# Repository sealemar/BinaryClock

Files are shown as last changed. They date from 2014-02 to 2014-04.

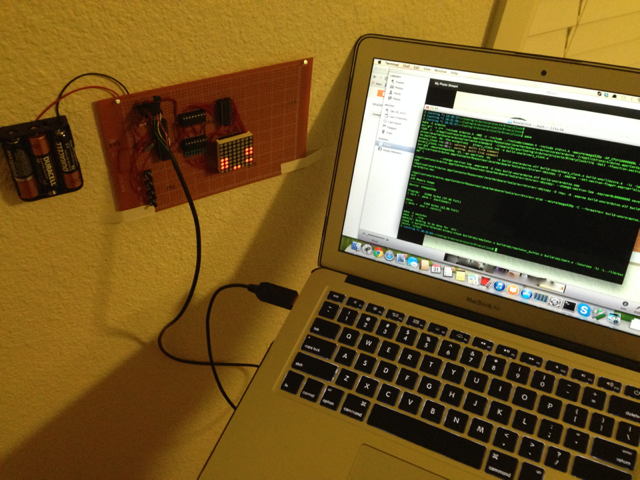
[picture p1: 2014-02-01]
doc/photos/BinaryClockProgramming.jpg

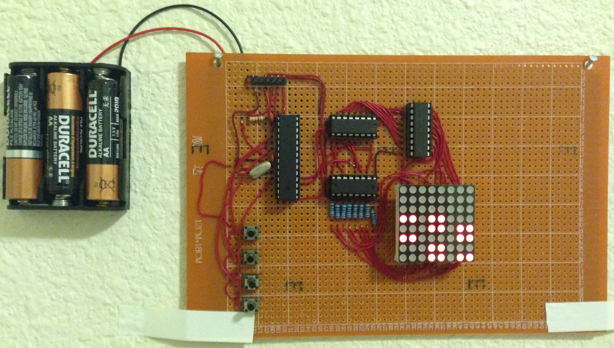
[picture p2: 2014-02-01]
doc/photos/BinaryClock.jpg

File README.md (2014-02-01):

BinaryClock
===========

More about the project is on my blog:

- [I talk about software](http://sealemar.blogspot.com/2014/02/binaryclock-binary-clock-diy.html)
- [I talk about hardware](http://sealemar.blogspot.com/2014/02/binaryclock-hardware.html)

Here I talk only about the tools which you will need to compile the software.

Tools I will need
-----------------

This is a list of tools you will (or may) need to work with the code. This list is described in more details on the [blog](http://sealemar.blogspot.com).

- [Make](http://www.gnu.org/software/make/manual/make.html) (*comes with every Unix based OS - Linux/Mac, etc.*)
- [Arduino software](http://arduino.cc/en/Main/Software)
- [Makefile by Sudar / Martin Oldfield](https://github.com/sudar/Arduino-Makefile)
- [colorgcc](https://github.com/colorgcc/colorgcc) (*optional, but is very handy when it comes to compiling code in the console/terminal*)
- [Exuberant ctags](http://ctags.sourceforge.net/) (*optional, but is very handy especially when it comes to Emacs or ViM*)

**For the emulator and tests:**
- gcc / clang (*at least one of these comes with every Unix based OS - Linux - gcc, MacOs - clang*)

**For the emulator:**
- ncurses (*comes with every Unix based OS*)

**For the vimproject (optional - read on):**
- ViM, [MacVim](https://code.google.com/p/macvim) for Mac

**For the schematic:**
- [Fritzing](http://fritzing.org)

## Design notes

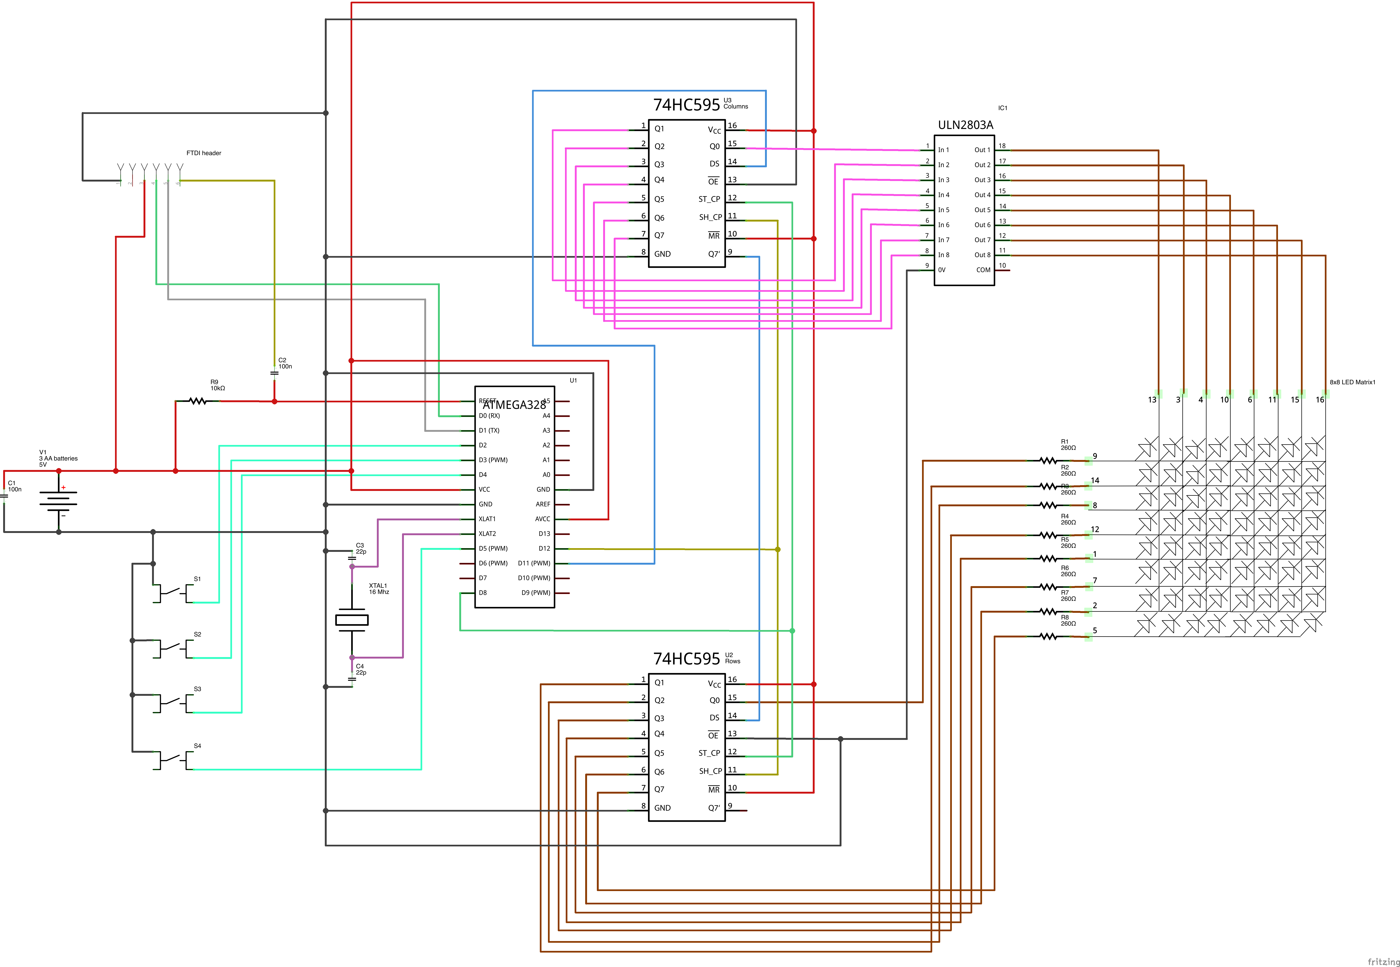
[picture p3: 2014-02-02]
doc/schematic/schematics.png

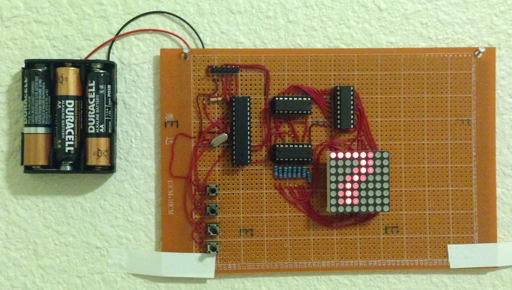
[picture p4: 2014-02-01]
doc/photos/BinaryClockSlidingTIme.jpg

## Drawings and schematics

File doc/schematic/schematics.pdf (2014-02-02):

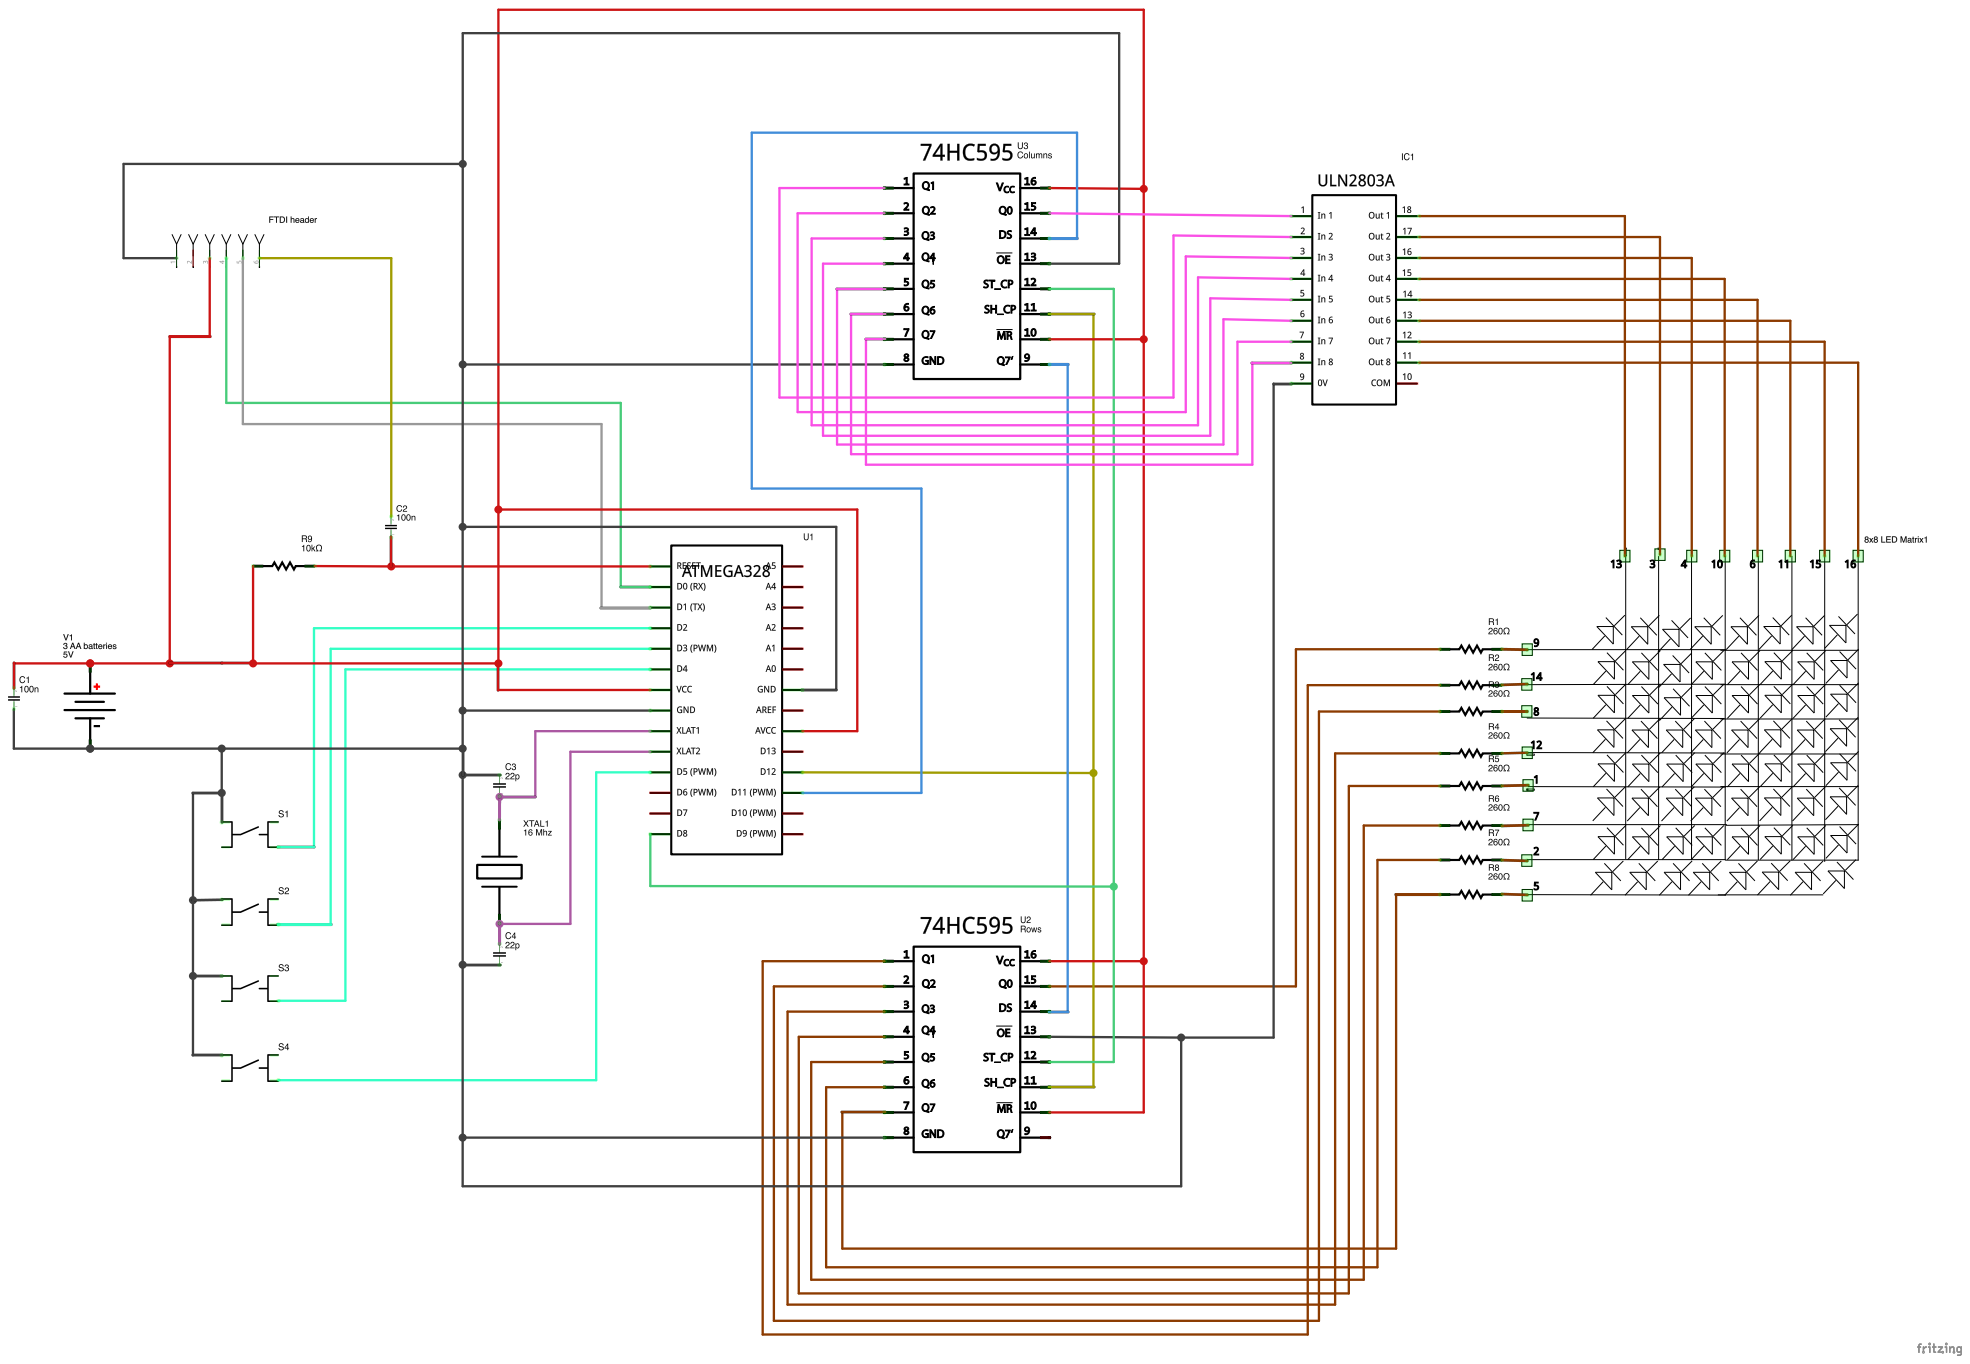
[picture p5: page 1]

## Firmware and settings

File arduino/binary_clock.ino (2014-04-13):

// Copyright [2013] [Sergey Markelov]
//
// Licensed under the Apache License, Version 2.0 (the "License");
// you may not use this file except in compliance with the License.
// You may obtain a copy of the License at
//
//     http://www.apache.org/licenses/LICENSE-2.0
//
// Unless required by applicable law or agreed to in writing, software
// distributed under the License is distributed on an "AS IS" BASIS,
// WITHOUT WARRANTIES OR CONDITIONS OF ANY KIND, either express or implied.
// See the License for the specific language governing permissions and
// limitations under the License.
//
// @brief BinaryClock Arduino implementation
//
// developed by Sergey Markelov (11/04/2013)
//

#include <clock_main.h>

//
// P1 -> 74HC595 [Q0]  \
// P2 -> 74HC595 [Q1]   \
// P3 -> 74HC595 [Q2]    \
// P4 -> 74HC595 [Q3]     \
// P5 -> 74HC595 [Q4]     /   1st Shift Register
// P6 -> 74HC595 [Q5]    /      Columns
// P7 -> 74HC595 [Q6]   /
// P8 -> 74HC595 [Q7]  /
//
// PA -> 74HC595 [Q0]  \
// PB -> 74HC595 [Q1]   \
// PC -> 74HC595 [Q2]    \
// PD -> 74HC595 [Q3]     \
// PE -> 74HC595 [Q4]     /   2st Shift Register
// PF -> 74HC595 [Q5]    /      Rows
// PG -> 74HC595 [Q6]   /
// PH -> 74HC595 [Q7]  /
//

#define DISPLAY_MILLIS 2
#define CLOCK_UPDATE_MILLIS 50

#define BUTTON_1_PIN 2
#define BUTTON_2_PIN 3
#define BUTTON_3_PIN 4
#define BUTTON_4_PIN 5

// Pin connected to ST_CP of 74HC595
#define LATCH_PIN 8
// Pin connected to SH_CP of 74HC595
#define CLOCK_PIN 12
// Pin connected to DS of 74HC595
#define DATA_PIN  11

static byte ScreenRows[CLOCK_PATTERN_SIZE] = { 0 };

static const int buttons[] = { BUTTON_1_PIN, BUTTON_2_PIN, BUTTON_3_PIN, BUTTON_4_PIN };
static ClockState clockState;
static unsigned long lastDisplayMillis     = 0;
static unsigned long lastClockUpdateMillis = 0;

static void display()
{
    //
    // A little trick:
    // Iterate beyond the end of ScreenRows, so that the last iteration
    // clears the screen:
    // (1 << 8) & 0xff = 0 -> clear screen
    // in that situation the last row won't stay lit permanently, but will
    // obey DISPLAY_MILLIS
    //
    for(size_t i = 0; i < countof(ScreenRows) + 1; ++i) {
        // Take the latchPin low so the LEDs don't change while you're sending in bits:
        digitalWrite(LATCH_PIN, LOW);

        // Shift out the bits
        // First shift rows, then columns, because shift register for rows comes after columns
        shiftOut(DATA_PIN, CLOCK_PIN, MSBFIRST, ScreenRows[i]);

        // Columns are cathodes, thus walking 0 should be used, but I account for
        // ULN2803, which inverts that
        // http://forum.arduino.cc/index.php?topic=78585.msg594284#msg594284
        // http://www.thebox.myzen.co.uk/Workshop/LED_Matrix.html
        shiftOut(DATA_PIN, CLOCK_PIN, MSBFIRST, 1 << i);

        // Take the latch pin high so the LEDs will light up:
        digitalWrite(LATCH_PIN, HIGH);
    }
}

static int arduino_setPixel(int x, int y, Bool turnOn)
{
    if(turnOn) {
        ScreenRows[x] |= 1 << y;
    } else {
        ScreenRows[x] &= ~(1 << y);
    }

    return 0;
}

static int arduino_uptimeMillis(unsigned long *milliseconds)
{
    *milliseconds = millis();
    return 0;
}

static int arduino_clearScreen()
{
    memset(&ScreenRows, 0, sizeof(ScreenRows));

    return 0;
}

static int arduino_initDateTime(DateTime *dt)
{
    memset(dt, 0, sizeof(DateTime));

    dt->year   = 2014;
    dt->month  = APRIL;
    dt->day    = 13;
    dt->hour   = 0;
    dt->minute = 10;
    dt->second = 0;

    return 0;
}

void setup()
{
    // Clock interface implementation
    clock_extern_setPixel     = arduino_setPixel;
    clock_extern_uptimeMillis = arduino_uptimeMillis;
    clock_extern_initDateTime = arduino_initDateTime;
    clock_extern_clearScreen  = arduino_clearScreen;

    // Set pins to output so you can control the shift register
    pinMode(LATCH_PIN, OUTPUT);
    pinMode(CLOCK_PIN, OUTPUT);
    pinMode(DATA_PIN,  OUTPUT);

    for(size_t i = 0; i < countof(buttons); ++i) {
        pinMode(buttons[i], INPUT);           // set pin to input
        digitalWrite(buttons[i], HIGH);       // turn on internal pullup resistors

        // Note that internal pull-up resistor switches the state of a button.
        // To check if a button is pressed, test digitalRead(ButtonPin) == LOW
    }

    clock_clearScreen();
    Call(clock_init(&clockState));
}

void loop()
{
    unsigned long m = millis();

    //
    // Update BinaryClock state
    // account for overflows
    //
    if(m < lastClockUpdateMillis || m - lastClockUpdateMillis > CLOCK_UPDATE_MILLIS) {
        for(size_t i = 0; i < countof(buttons); ++i) {
            Call(clock_button_press( &(clockState.buttons), i, digitalRead(buttons[i]) == LOW ? TRUE : FALSE));
        }

        Call(clock_update(&clockState));
        m = lastClockUpdateMillis = millis();
    }

    //
    // Display
    // account for overflows
    //
    if(m < lastDisplayMillis || m - lastDisplayMillis > DISPLAY_MILLIS) {
        display();
        lastDisplayMillis = millis();
    }
}

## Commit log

2013-11-11 +) YouCompleteMe +) Added subdirectories: arduino, lib, emulator, test, include each of those have their own Makefile +) unit tests for clock::slidePattern()
2013-11-14 *) Makefile changes to make it compile and link on Raspberry Pi (ARM) as well as on x86
2013-11-14 *) Removed separate definition and switched from gcc back to clang
2013-11-14 *) Emulator works and draws the alphabet. To draw one character back press 'h' or 'k', to draw one character forward press any other key. Press Esc to quit
2013-11-16 +) A little testing framework was implemented which produces this kind of output:
    --- tests.c:21 (main) - a test suite started ---
    --- ut_clock.c:239 (ut_clock_tests) - a test suite started ---
    Error: ut_clock.c:172 (test_clock_drawPattern_correct) - [-48] pattern CLOCK_ALPHABET[CLOCK_1] doesn't match the screen
    ----> test_ut/test_ut.c:21 (_runTestSuite) - [-48]
    --- ut_clock.c:239 (ut_clock_tests) - a test suite completed --- 4 test(s) ran. 3 succeded, 1 failed
    ----> test_ut/test_ut.c:21 (_runTestSuite) - [1]
    --- tests.c:21 (main) - a test suite completed --- 1 test(s) ran. 0 succeded, 1 failed
    +) The following tests were implemented:
    TestUnit testSuite[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
2013-11-18 *) test_ut now prints which unit it currently runs
2013-11-19 *) lib/clock_time.c::DateTime now has milliseconds +) unit tests for lib/clock_time.c::clock_addMillisToDateTime()
2013-11-25 +) include/common.h --- version information +) emulator --- sections: - Banner - ClockFace - Buttons - Notes
2013-11-25 +) emulator/clock_extra --- buttons
2013-11-27 *) Working towards implementation for the buttons
2013-11-27 *) Working towards implementation of the buttons
2013-11-28 +) lib/clock_button and corresponding unit tests. Current implementation can operate on up to 4 buttons
2013-11-28 +) emulator/emulator_button -- buttons work. Not connected yet
2013-11-28 +) lib/clock_state::ClockState.frameMillis -- current frame time (for animation), i.e. those steps which slide text can use it to show the next frame only after the _frameMillis_ exceeds some amount
2013-11-29 +) emulator/emulator_button -- now displays information next to each button with what that button does in the current context
2013-11-29 +) lib/date_time::date_time_dateToStr(const DateTime *dt, char str[DATE_TIME_DATE_STR_SIZE]) prints date from _dt_ to _str_ in format MMM DD YYYY
    +) lib/date_time::date_time_timeToStr(const DateTime *dt, char str[DATE_TIME_TIME_STR_SIZE])
    prints time from _dt_ to _str_ in format
    hh:mm:ss
    +) unit tests for both functions
    +) lib/date_time::DateTimeMonthsStr --- an array of three letter months
2013-11-30 +) lib/clock_main -- CLOCK_STATE_SET_DATE
    The clock now shows time and date. Both can be set. Date adjustments account
    for changes in year and month for days, i.e. if it is Jan 31 2016 and the
    month is increased to Feb, then days will be automatically set to 29.
    Now if the year is increased to 2015, the days will be switched to 28
2013-11-30 *) All extern functions which an implementation must or may want to (for some funcitons) override are now declared in lib/clock_extern_functions.h and stubbed to NULL by default
    +) lib/clock_extern_functions.c::clock_initDateTime(DateTime *) an
    implementation may define this function. If it is not NULL,
    lib/clock_main.c::clock_init(ClockState *) will call it to initialize
    ClockState->DateTime. I.e. an implementation may define the function to
    set the date and time to current date and time
2013-12-05 *) Makefile -- don't cancel make job if Arduino make fails
2013-12-08 +) lib/clock_main -- clock_event bindings *) lib/date_time::date_time_dateToStr() now prints day of week
2013-12-09 *) working on Arduino part -- compiles !!! *) lib/*.h --> \#ifdef __cplusplus extern "C" { \#endif
2013-12-12 +) arduino works!!!
2013-12-13 *) changed travelling row bit to travelling column bit to eliminate this nasty flickering:
    http://forum.arduino.cc/index.php?topic=204377
    https://www.youtube.com/watch?v=ivCGI88enM8
2013-12-19 +) arduino/Makefile --- ISP definitions +) ULN2803 on hardware side to not overstress on a walking column *) the code in arduino/binary_clock.ino is changed to account for the ULN
2014-01-02 *) use internal pull up resistors on buttons
2014-01-02 +) doc/schematic/ Eagle CAD schematic and Fritzing CAD project
    [BinaryClock.brd, BinaryClock.sch, Fritzing-BinaryClock.fzz]
2014-01-13 arduino/binary_clock.ino: no pull-down resistors on buttons, uses internal ATMEGA328 pull-up resistors instead. Uses pins 2-5 for buttons. No duty cycle as 260 Ohm resistors on rows with 3 AA batteri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
2014-01-15 Adding 'LED Matrix LD1088-BS' Fritzing part
2014-01-15 Fritzing schematic
    [Fritzing-BinaryClock.fzz]
2014-01-15 +) Fritzing part - FTDI Basic Male Header +) FTDI on schematics
    [Fritzing-BinaryClock.fzz]
2014-01-17 Schematics is ready for 2 x 74HC595, ULN2803A
    [Fritzing-BinaryClock.fzz]
2014-01-19 arduino/Makefile: A better error description on missing ARDMK_DIR environment variable
2014-01-19 arduino/binary_clock.ino: introduced update intervals, one for interacting with the clock and the other for displaying the data on the screen. The intervals are supposed to save power consumption
2014-01-19 arduino/binary_clock.ino: fixed wrong comment
    [binary_clock.ino]
2014-02-01 -) Eagle CAD files *) README.md Fritzing home page fix
    [BinaryClock.brd, BinaryClock.sch]
2014-02-02 *) Fixed error in schematics as per http://forum.arduino.cc/index.php?topic=204377.msg1572493#msg1572493
    [Fritzing-BinaryClock.fzz]
2014-04-13 *) Fixed clock_event_updateList() logic. If the date was first increased and then decreased and that manipulation went through a ClockEvent, then that ClockEvent will stay calculated as for the next 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
    [binary_clock.ino]
